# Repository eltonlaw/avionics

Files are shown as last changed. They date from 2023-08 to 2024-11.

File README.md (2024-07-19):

# quadcopter

    ├── avrlib: Shared utils
    ├── devtools: miscellaneous local dev stuff
    │   ├── blinky: Basic hex file to flash for testing hardware
    │   ├── cli: To replace x.sh
    │   └── serial_interactive.py: interactive uart with ipython
    ├── fc1: 
    │   ├── fc1board: Kicad files
    │   └── src: Firmware
    ├── kicad_sym: Shared symbols lib
    ├── sensor_calibrate: 3d printed test bench for simulating flight. ESP32 webserver connected to a servo.
    └── x.sh: Manages building/flashing/testing etc.

## Setup

Sets up environment vars and builds the CLI, a `./x` executable

```
./build_cli.sh
direnv allow .
```

### ESP32

Set `export ESP_IDF_PATH=...` in your shell profile

```
git clone https://github.com/espressif/esp-idf ${ESP_IDF_PATH}
${ESP_IDF_PATH}/install.sh esp32c3 --enable-pytest
${ESP_IDF_PATH}/tools/idf_tools.py install
```

### STM32

```
sudo pacman -S arm-none-eabi-gcc arm-none-eabi-newlib
```

[Download STM32CubeProgrammer](https://www.st.com/en/development-tools/stm32cubeprog.html#get-software) and add to \$PATH

## Flash with OpenOCD

```
# Start server
$ openocd -f ext/openocd/tc/board/st_nucleo_g0.cfg
# In separate terminal, connect to openocd server
$ telnet localhost 4444
> reset halt
> flash write_image erase ./fc3/build/fc3-G0.hex
> reset run
```
## Yocto

```
sudo pacman -S rpcsvc-proto chrpath cpio diffstat inetutils glibc
```

## BOM

https://www.digikey.ca/en/mylists/list/2G2K0KZVBX

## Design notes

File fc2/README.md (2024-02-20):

# fc2

## fc2_board

- MPU6050 REGOUT (pin 10) needs 0.1uF regulator filter cap [^1]
- MPU6050 VDD (pin 13) needs 0.1uF bypass cap [^1]
- MPU6050 CPOUT (pin 20) needs 2.2nF charge pump cap [^1]
- MPU6050 VLOGIC (pin 8) needs 10nF bypass cap [^1]
- MPU6050 FSYNC (pin 11) connect to GND since frame synchronization digital input unused [^1]
- MPU6050 FSYNC (pin 1) connect to GND since external reference clock unused [^1]
- MPU6050 SDA (pin 24) and SCL (pin 23) pins need pull up resistors to VDD [^1]
- MPU6050 AD0 (pin 9) pulled to ground so that i2c address is 1101000 (shifted format it would be 0xD0 for write and 0xD1 for read) [^1]
- MPU6050 INT (pin 12) is an output pin to signal events. Since we're continuously polling, this is unused. [^1]
- MPU6050 AUX_DA (pin 6) and AUX_CL (pin 7) are for an external magnetometer and are unused. [^1]
- D1 LED for showing board is powered
- SAM-M10Q "power consumption of 37mW in continuous tracking mode with four concurrent GNSS" [^3]
- SAM-M10Q "The inrush current at startup can go up to 100 mA. Ensure that the external power supply is able to deliver up to 100 mA." [^3]
- SAM-M10Q "All the inputs have internal pull-up resistors in normal operation and can be left open if not used." [^3]
- SAM-M10Q V_IO and V_CC typical value is 3V with max of 3.6V and min of 2.7V
- SAM-M10Q "The inrush current at startup can go up to 100 mA" [^3]
- SAM-M10Q "all inputs have internal pull-up resisotrs in normal operation and can be left open if unused" [^3]
- SAM-M10Q "not protected against overvoltage or reversed voltages." [^3]

[^1]: https://invensense.tdk.com/wp-content/uploads/2015/02/MPU-6000-Datasheet1.pdf
[^2]: https://www.st.com/resource/en/datasheet/stm32g070cb.pdf
[^3]: https://content.u-blox.com/sites/default/files/documents/SAM-M10Q_DataSheet_UBX-22013293.pdf

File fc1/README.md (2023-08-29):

# fc1

## Design

For the first iteration of this flight computer going to start with an atmega328p as the controller. Mainly because there's a lot of code + documentation supporting it from the Arduino ecosystem.

## fc1board

- LED connected to VCC to show when its powered
- For atmega328p
    - exposed UART and SPI pin headers for flashing & development
    - Using UART for debugging so an external crystal oscillator will be necessary, need to manually calibrate it. Factory calibration accuracy of the internal RC oscillator at 8.0MHz is +-2% with Vcc=3V,Temperature=25C and +-14% with Vcc=2.7V-5.5V,Temperature=-40C-125C.
    - Might need an external oscillator so that it can communicate with the MPU6050 faster which can do up to i2c@400kHz and atmel recommends at least 16 times higher than SCL frequency. 
    - external pull up resistors required for atmega 328p i2c pins, not specified in datasheet but 4.7k seemed like a commonly used amount when searching online
    - external 10 kiloohm pull up resistor for 1/PC6/RESET so it doesn't reset
- For MPU-6050, connected via i2c
    * Pin descriptions from datasheet
        - CLKIN/1, optional external ref clock input, connected to ground since unused
        - AUX_DA/6 and AUX_CL/7 not connected because not using external sensors
        - VLOGIC/8, digital I/O supply voltage connected to 3.3V with 10nF decoupling cap
        - AD0/9 i2c slave addres or spi serial data output; grounded
        - REGOUT/10, regulator filter capactior connection connected to 0.1uF decoupling cap
        - VDD/13, power supply voltage and digital I/O supply voltage. connected to 3.3V with 0.01uF decoupling cap
        - CPOUT/20 charge pump capacitor connection, connected to 2.2nF cap to ground
        - Not connected: 2, 3, 4, 5, 14, 15, 16,17, 19, 21, 22
    * copied some wiring from gy-521 (breakout board for MPU-6050)
        - INT/12 has 4.7k pull up resistor
    * If AD0=0 i2c address is 1101000 (0x68), if AD0=1 i2c address is 1101001 (0x69). No pull up resistor. Used for interacting with several sensors at once. Just have one so connecting to ground to use 0x68. 
    * AUX_DA, AUX_CL
    * VDD rated for -0.5V to +6V
    * Sensor needs some time to calibrate when it just gets started (and when it's stationary)
    * i2c operates at 400kHz
    * "Gyro, accelerometer and temperature measurement data are read-only registers accessed via the serial interface. Data from these registers may be read anytime"

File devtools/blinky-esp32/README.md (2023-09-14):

# blinky-esp32

```
cd $IDF_PATH
./install.sh esp32c3
```

```
idf.py flash
idf.py monitor
```

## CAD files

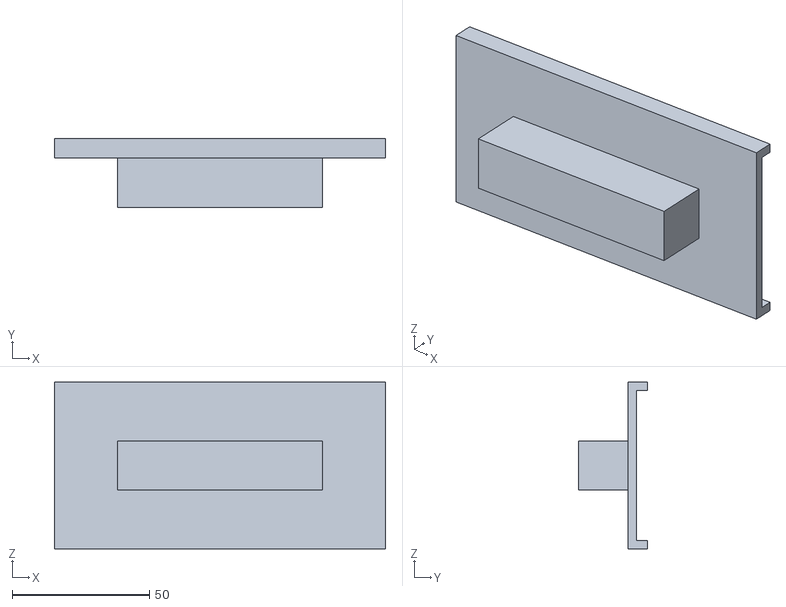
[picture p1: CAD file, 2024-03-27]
stl/BreadboardVise_v1.stl
120.6 x 25.0 x 60.8

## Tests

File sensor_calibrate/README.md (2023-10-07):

## Dev

Assuming you've followed the [basic setup](../README.md#setup)

Enable the esp environment

```
direnv allow .
idf.py set-target esp32c
```

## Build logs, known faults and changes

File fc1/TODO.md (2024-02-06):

- [ ] 3 separate phases - ready/calibrating/ready-to-launch
- [ ] separate phases - ready/calibrating/ready-to-launch/in-flight/retrieval
    * [ ] ready: waiting for instructions to begin calibration
    * [ ] calibration: 
    * [ ] ready-to-launch: check that igniter is connected and that IMU is calibrated
    * [ ] launching: 
    * [ ] in-flight
    * [ ] retrieval

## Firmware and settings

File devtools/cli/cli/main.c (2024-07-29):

#include <errno.h>
#include <stdio.h>
#include <stdlib.h>
#include <string.h>
#include <unistd.h>
#include "buildtools.h"

typedef int (*command_fn)(int, char**);

int help(int argc, char **argv);

typedef struct {
    char *type;
    command_fn fn;
    char *description;
} command;

int serial(int argc, char **argv) {
    return system("ipython -i -c \"%load devtools/serial_interactive.py\"");
}

int avr_gcc(int argc, char **argv) {
    return system("avr-gcc -print-search-dirs");
}

int fc1(int argc, char **argv) {
    return make(argc, argv, "./build/fc1");
}

int fc3(int argc, char **argv) {
    int err;
    if (0 != (err = cmake("fc3"))) {
        fprintf(stderr, "Error running cmake: %s\n", strerror(err));
        return err;
    }
    if (0 != (err = system("cp build/fc3/compile_commands.json ."))) {
        fprintf(stderr, "Error copying compile_commands.json: %s\n", strerror(err));
        return err;
    }
    return make(argc, argv, "./build/fc3");
}

int sensor_calibrate(int argc, char **argv) {
    return system("cd sensor_calibrate && idf.py build");
}

int sim(int argc, char **argv) {
    return system("cd ./physics_sim/build && cmake ../ && make && ./sim");
}

int gen_compile_commands(int argc, char **argv) {
    int err;
    if (0 != (err = system("cmake -Bfc3/build fc3")))
        return err;
    /* If compile_commands.json already exists, skip soft linking it */
    if (0 == (err = access("compile_commands.json", R_OK)))
        return err;
    if (0 != (err = system("ln -s fc3/build/compile_commands.json .")))
        return err;
    return err;
}

int gdb(int argc, char **argv) {
    if (argc < 3) {
        fprintf(stderr, "Usage: %s <elf file>\n", argv[0]);
        return EINVAL;
    }
    char cmd[256];
    snprintf(cmd, sizeof(cmd), "arm-none-eabi-gdb %s -x devtools/.gdbinit", argv[2]);
    printf("%s\n", cmd);
    return system(cmd);
}

int openocd(int argc, char **argv) {
	return system("openocd -f interface/stlink.cfg -f target/stm32g0x.cfg  -s ext/openocd/tcl");
}

command commands[] = {
    {"avr-gcc", avr_gcc, "Show location of avr gcc libraries"},
    {"fc1", fc1, "Compile and flash FC1"},
    {"fc3", fc3, "Compile and flash FC3"},
    {"gdb", gdb, "Start gdb server"},
    {"gen-compile-commands", gen_compile_commands, "Generate compile_commands.json for LSP"},
    {"openocd", openocd, "Start openocd server"},
    {"sensor-calibrate", sensor_calibrate, "Build ESP32 sensor calibration app"},
    {"serial", serial, "Start ipython repl loading in pyserial utils"},
    {"sim", sim, "Build and start physics sim"},
    {"info", help, "Display help"},
    {NULL, NULL, NULL}
};

int help(int argc, char *argv[]) {
    printf("Available commands:\n");
    for (int i = 0; commands[i].type != NULL; i++) {
        printf("  %s: %s\n", commands[i].type, commands[i].description);
    }
    return 0;
}

int main(int argc, char *argv[]) {
    int err;
    if (argc < 2)
        goto invalid_input;

    for (int i = 0; commands[i].type != NULL; i++) {
        if (strcmp(argv[1], commands[i].type) == 0) {
            if (0 == (err = commands[i].fn(argc, argv)))
                return err;
            fprintf(stderr, "ERROR: %s\n", strerror(err));
            return 1;
        }
    }
invalid_input:
    printf("Usage: %s <command>\n", argv[0]);
    help(argc, argv);
    return 1;
}

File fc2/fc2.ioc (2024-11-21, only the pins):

Mcu.UserName=STM32G070RBTx
PA10.Signal=I2C1_SDA
PA13.GPIO_Label=TMS
PA13.Signal=SYS_SWDIO
PA14-BOOT0.GPIO_Label=TCK
PA14-BOOT0.Signal=SYS_SWCLK
PA2.Signal=USART2_TX
PA3.Signal=USART2_RX
PA5.GPIO_Label=LED_GREEN
PA5.Signal=GPIO_Output
PA9.Signal=I2C1_SCL
PB10.Signal=I2C2_SCL
PB11.Signal=I2C2_SDA
PC11.Signal=USART3_RX
PC13.Signal=SYS_WKUP2
PC4.Signal=USART3_TX

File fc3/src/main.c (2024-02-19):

#include <string.h>
#if defined FC3_G0
  #include "stm32g0xx_hal.h"
  #include "stm32g0xx_hal_conf.h"
#elif defined FC3_F1
  #include "stm32f1xx_hal.h"
#endif

#define LED_GREEN_Pin GPIO_PIN_5
#define LED_GREEN_GPIO_Port GPIOA

UART_HandleTypeDef huart2;

void Error_Handler(void) {
  __disable_irq();
  while (1) { }
}

void SystemClock_Config(void)
{
  RCC_OscInitTypeDef RCC_OscInitStruct = {0};
  RCC_ClkInitTypeDef RCC_ClkInitStruct = {0};

  /** Configure the main internal regulator output voltage
  */
  HAL_PWREx_ControlVoltageScaling(PWR_REGULATOR_VOLTAGE_SCALE1);

  /** Initializes the RCC Oscillators according to the specified parameters
  * in the RCC_OscInitTypeDef structure.
  */
  RCC_OscInitStruct.OscillatorType = RCC_OSCILLATORTYPE_HSI;
  RCC_OscInitStruct.HSIState = RCC_HSI_ON;
  RCC_OscInitStruct.HSIDiv = RCC_HSI_DIV1;
  RCC_OscInitStruct.HSICalibrationValue = RCC_HSICALIBRATION_DEFAULT;
  RCC_OscInitStruct.PLL.PLLState = RCC_PLL_NONE;
  if (HAL_RCC_OscConfig(&RCC_OscInitStruct) != HAL_OK)
    Error_Handler();

  /** Initializes the CPU, AHB and APB buses clocks
  */
  RCC_ClkInitStruct.ClockType = RCC_CLOCKTYPE_HCLK|RCC_CLOCKTYPE_SYSCLK
                              |RCC_CLOCKTYPE_PCLK1;
  RCC_ClkInitStruct.SYSCLKSource = RCC_SYSCLKSOURCE_HSI;
  RCC_ClkInitStruct.AHBCLKDivider = RCC_SYSCLK_DIV1;
  RCC_ClkInitStruct.APB1CLKDivider = RCC_HCLK_DIV1;

  if (HAL_RCC_ClockConfig(&RCC_ClkInitStruct, FLASH_LATENCY_0) != HAL_OK)
    Error_Handler();
}

static void MX_GPIO_Init(void) {
  GPIO_InitTypeDef GPIO_InitStruct = {0};

  /* GPIO Ports Clock Enable */
  __HAL_RCC_GPIOC_CLK_ENABLE();
  __HAL_RCC_GPIOF_CLK_ENABLE();
  __HAL_RCC_GPIOA_CLK_ENABLE();

  /*Configure GPIO pin Output Level */
  HAL_GPIO_WritePin(LED_GREEN_GPIO_Port, LED_GREEN_Pin, GPIO_PIN_RESET);

  /*Configure GPIO pin : LED_GREEN_Pin */
  GPIO_InitStruct.Pin = LED_GREEN_Pin;
  GPIO_InitStruct.Mode = GPIO_MODE_OUTPUT_PP;
  GPIO_InitStruct.Pull = GPIO_NOPULL;
  GPIO_InitStruct.Speed = GPIO_SPEED_FREQ_HIGH;
  HAL_GPIO_Init(LED_GREEN_GPIO_Port, &GPIO_InitStruct);
}


static void MX_USART2_UART_Init(void) {
  huart2.Instance = USART2;
  huart2.Init.BaudRate = 115200;
  huart2.Init.WordLength = UART_WORDLENGTH_8B;
  huart2.Init.StopBits = UART_STOPBITS_1;
  huart2.Init.Parity = UART_PARITY_NONE;
  huart2.Init.Mode = UART_MODE_TX_RX;
  huart2.Init.HwFlowCtl = UART_HWCONTROL_NONE;
  huart2.Init.OverSampling = UART_OVERSAMPLING_16;
  huart2.Init.OneBitSampling = UART_ONE_BIT_SAMPLE_DISABLE;
  huart2.Init.ClockPrescaler = UART_PRESCALER_DIV1;
  huart2.AdvancedInit.AdvFeatureInit = UART_ADVFEATURE_NO_INIT;
  if (HAL_UART_Init(&huart2) != HAL_OK)
    Error_Handler();
  if (HAL_UARTEx_SetTxFifoThreshold(&huart2, UART_TXFIFO_THRESHOLD_1_8) != HAL_OK)
    Error_Handler();
  if (HAL_UARTEx_SetRxFifoThreshold(&huart2, UART_RXFIFO_THRESHOLD_1_8) != HAL_OK)
    Error_Handler();
  if (HAL_UARTEx_DisableFifoMode(&huart2) != HAL_OK)
    Error_Handler();
}

int main(void) {
  HAL_Init();
  SystemClock_Config();
  MX_GPIO_Init();
  MX_USART2_UART_Init();

  char buf[] = "hello world\n";
  while(1) {
    HAL_UART_Transmit(&huart2, (uint8_t *)buf, strlen(buf), HAL_MAX_DELAY);
    HAL_GPIO_TogglePin(LED_GREEN_GPIO_Port, LED_GREEN_Pin);
    HAL_Delay(1000);
  }
  return 0;
}

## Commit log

2023-08-01 fix: fc1 cleanup build process
    [serial_interactive.py]
2023-08-12 feat: add initial board setup
    [fc1board.kicad_pcb, fc1board.kicad_sch]
2023-08-27 chore: add kicad gitignore
2023-08-28 read mpu6050 data using i2c
2023-08-28 chore: move mpu6050 i2c code into device file
2023-08-29 chore: i2c_start returns avcerr_t
2023-08-29 feat: add kicad_sym
2023-08-31 chore: %u sensor data zero-padded when printing
2023-08-31 fix: mpu6050 disable sleep mode on init
    [main.c, mpu6050.c]
2023-09-01 fix: add missing import os
    [serial_interactive.py]
2023-09-01 feat: add accel/gyro config
2023-09-02 chore: move pin macros into enums
2023-09-02 feat: set gyro/accel scaler on init
2023-09-04 feat: init sensor_calibrate
2023-09-09 init pt.2 sensor calibration
2023-10-07 init fc2 esp32c3 based
2023-10-22 feat: read data off IMU and log
2023-10-22 feat: add error checking on i2c read/writes
    [mpu6050.c]
2023-10-22 fix: add missing stdio include
    [main.c]
2023-10-30 feat: add logging through UART
2023-11-06 feat: calibrate mpu6050 with avg of 700 reads
2023-11-12 fix: cleanup glfw when window create failed
    [main.cpp]
2023-11-13 fix: serial term dont print empty nl
    [main.c, serial_interactive.py]
2023-11-19 add stm32cubeide Debug/* to gitignore
2023-11-19 fix: accel_z should read 1g
    [mpu6050.c]
2023-12-27 fix: logging levels bad filtering + panic
    [error.c, log.c]
2023-12-28 feat: init fc2 kicad proj w mpu6050 wiring
    [fc2_board.kicad_pcb, fc2_board.kicad_sch]
2024-01-07 feat: add power on LED
    [fc2_board.kicad_sch]
2024-02-06 feat: cmake build for stm32g07rb
    Run inside fc3/
    rm -rf build && cmake -Bbuild . && make -C build
    # rm -rf build && cmake -Bbuild -DCMAKE_TOOLCHAIN_FILE=${CMAKE_CURRENT_SOURCE_DIR}/../ext/stm32-cmake/cmake/stm32_gcc.cmake . && make -C build
    Still has some issues, `make build` fails but it links and builds the
    executable.
    [main.c]
2024-02-09 feat: elf built with cmake
    - add_definitions so they're accesible from .c/.h
    - target_include_directories for src/ so that stm32g0xx_hal_conf.h can
    be linked
    - need to include stm32g0xx_hal_conf.h first otherwise bunch of errors
    with undefined stuff
    - copied stm32g0xx_hal_conf.h from fc2, this will be cleaned up in
    following PR
    [main.c]
2024-02-11 feat: compile and link uart ex module
2024-02-14 feat: add blinking debug led pin
2024-02-19 chore: add STM32CubeIde build commands for reference
2024-02-20 kicad: add SAM-m10q to fc2
    [fc2_board.kicad_sch]
2024-02-21 fix: accel and gyro offsets reversed so it can be added
    [mpu6050.c]
2024-02-23 Revert "fix: accel and gyro offsets reversed so it can be added"
    This reverts commit ef593b163291fe6d7abd8a64180ea10b6193a48a.
    [mpu6050.c]
2024-02-24 feat: TIM3 prescaled for 1ms accuracy
    to be used in calculating velocity
2024-02-24 add led flash when custom init starts
2024-03-04 feat: error handling+retry for failed MPU6050 init [#11]
    MPU6050 init has multiple HAL I2C calls
    - check WHOAMI = 0x68
    - pwr management module, sleep flag disabled
    - set gyro range
    - set accel range
    A bool was added in mpu6050_cfg whenever each discrete setup step was
    finished. This is used to track progress so we can have a small wrapper
    fn that continuously retries `mpu6050_init` until it returns E_OK or
    hits the max retry count. `mpu6050_init` uses the state info from those
    bools to conditionally run the setup code so anything thats been run
    already doesnt get run again.
    [fc2.ioc, main.c, mpu6050.c]
2024-03-05 feat: bump i2c1 to fast mode
    [fc2_board.kicad_sch]
2024-03-05 fix: adjust i2c pull up resistor for extra dev
    GY-521 breakout board uses a 4.7K for the MPU6050 and the Sparkfun
    Breakout board for the SAM M10Q uses 2.2K.
    Total Capacitance:
    - MPU6050: <5pF
    - STM32G070RB: 5pF
    - SAM M10Q: 10pF
    - Trace/Pad/Stray/Wire etc.: ??
    For I2C fast at 3.3V with a conservative estimate of total 100pF bus
    capacitance:
    - R_pu_min is 1.1K
    - R_pu_max of 3.54K
    Not going to worry about power drain so just going to set R_pu at 1.5K
    [fc2_board.kicad_sch]
2024-03-07 fix: add back unstaged sam-m10q kicad_mod
2024-03-13 feat: enable fc3 timer
2024-03-19 chore: add stm32cube IDE ignores
2024-03-27 init test stand
    [BreadboardVise_v1.stl]
2024-03-31 feat: loop rl in background thread
2024-04-03 feat: connect to different serial devices via profiles
2024-04-17 fix: main log bad formatting
    [main.c, serial_interactive.py]
2024-04-17 feat: uart read imu event data to file for analysis
2024-04-18 feat: sim read in sensor data
2024-04-27 feat: add generated imu logs for testing
2024-04-30 feat: add complementary filter for angular pos
2024-07-19 add bom
2024-07-20 kicad: add esc integration
    [fc2_board.kicad_sch]
2024-07-22 init i2c2 for bme280
2024-07-22 kicad: add BME280
    [fc2_board.kicad_sch]
2024-07-23 bme280: device initialization with i2c2
2024-07-25 bme280: read from nvm hard coded comp values for temp+pressure
2024-07-25 bme280: read compensated pressure and temp
2024-07-28 kicad: add label to batt
    [fc2_board.kicad_sch]
2024-07-30 fix: bme280 i2c addr
    [bme280.h, main.c]
2024-11-21 add fc2 stm32cubeide build + flash config
2024-11-22 fix: properly assign err values during bme280 configuration
    [bme280.c]
2024-12-10 feat: move main app out of stm32 generated main.c
2024-12-11 chore: error handling refactor
    [quadcopter.c]
2024-12-11 bme280: read pressure data and avg with imu data for altitude
